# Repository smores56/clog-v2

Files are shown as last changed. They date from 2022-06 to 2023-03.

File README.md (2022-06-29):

The Clog V2
===========

The Clog V2 is a 34-key split keyboard. It has the following features:

- Choc V1 switches
- Wireless only with Seeeduino Xiao BLE controllers
- Pinky clusters (top pinky keys on the sides)
- Splay (4° between middle and ring, 8° between ring and pinky)
- SplitKB puck support for tenting
- EVQWGD001 roller support

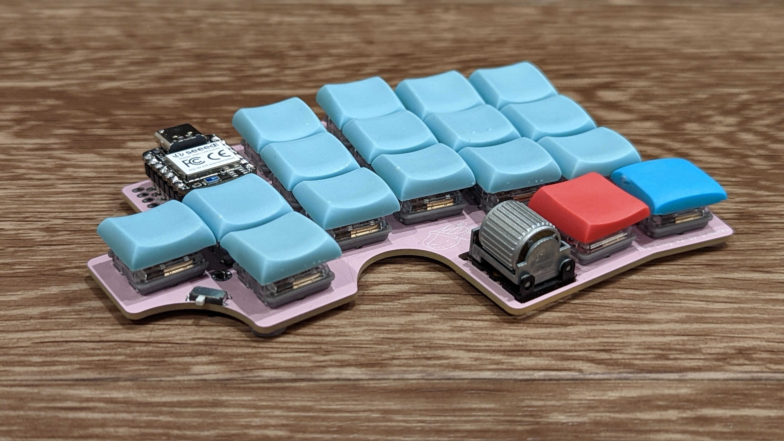
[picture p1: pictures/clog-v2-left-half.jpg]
One Half of the Clog V2


## How to Order

The [gerber ZIP](./clog-v2.zip) has everything you'll need to get this printed.
You can order from [JLC](https://jlcpcb.com) by just uploading that ZIP archive and keeping
the default options. I'd suggest removing the order number, otherwise they'll put
one on the board somewhere randomly.

## Building

### Parts Needed

Part Name            | Quantity        | Notes                                    | Link
--------------------:|:---------------:|:----------------------------------------:|:----
PCB                  | 2 (halves)      |                                          | Look up hurr hurr
Choc V1 Switches     | 34              |                                          | <https://mkultra.click/choc-switches>
Choc Keycaps         | 34              |                                          | <https://mkultra.click/mbk-factory-colors>
SMD Diodes           | 34              |                                          | <https://www.aliexpress.com/item/3256802562651339.html>
Power Switches       | 2               | Technically optional                     | <https://www.digikey.com/en/products/detail/nidec-copal-electronics/CUS-12TB/1124222>
Xiao BLE             | 2               | Not technically optional                 | <https://www.seeedstudio.com/Seeed-XIAO-BLE-nRF52840-p-5201.html>
Small LiPo Batteries | 2               |                                          | <https://www.aliexpress.com/item/2251832610867849.html>
Inch of Copper Wire  | 1               | Use thin and sheathed                    | Any hardware store
MCU Sockets          | 1 strip to chop | Optional, chop into sections of 7 pins   | <https://www.digikey.com/en/products/detail/mill-max-manufacturing-corp/316-43-164-41-006000/1212147>
MCU Socket Pins      | 28              | Optional, buy extras, these are slippery | <https://www.digikey.com/en/products/detail/mill-max-manufacturing-corp/3320-0-00-15-00-00-03-0/4147392>

### Tips

I'd solder the parts in this order:

- Diodes
- Power switches
- MCU sockets/Headers that came with the Xiao's
- MCU pins if you're [socketing](https://docs.splitkb.com/hc/en-us/articles/360011263059-How-do-I-socket-a-microcontroller-)
- Batteries (To the +ve and -ve terminals)
- The "bodge" wire from the +ve charging pad on the controller to the "Bdg" hole
- Choc switches

## Pictures

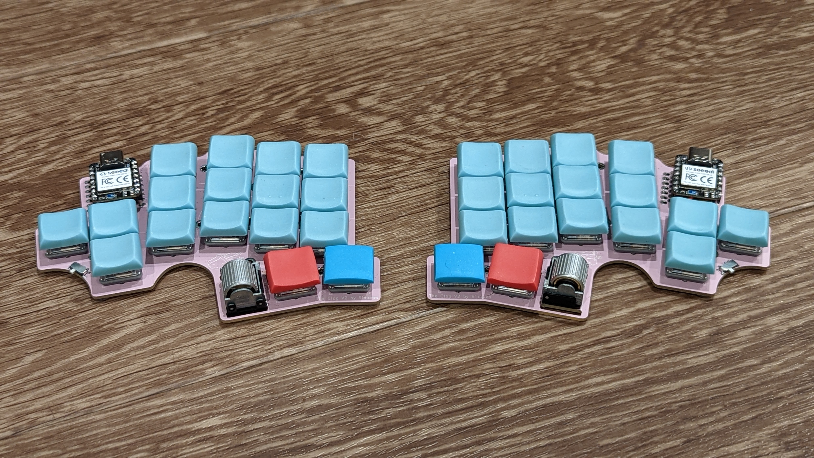
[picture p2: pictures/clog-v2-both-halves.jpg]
The Clog V2


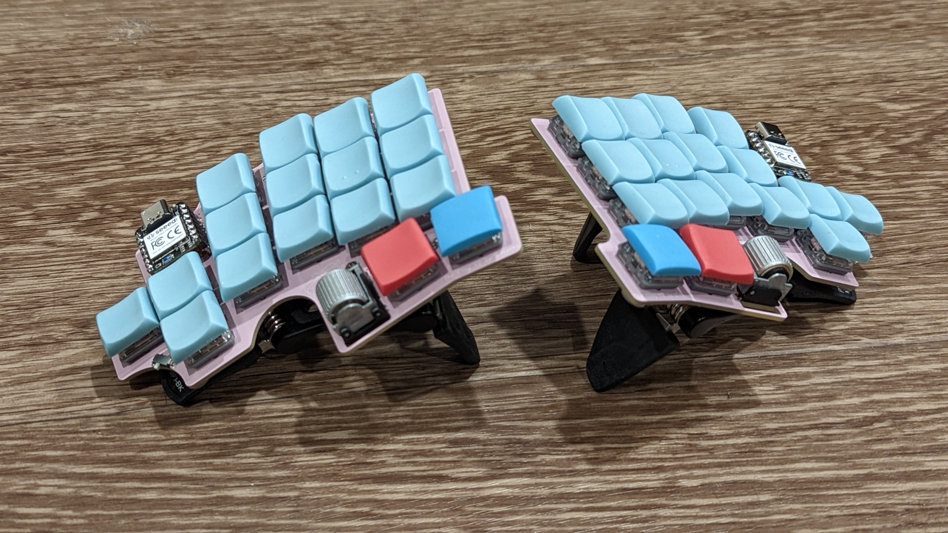
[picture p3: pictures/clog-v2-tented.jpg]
Tented with Pucks and Manfrotto Tripods


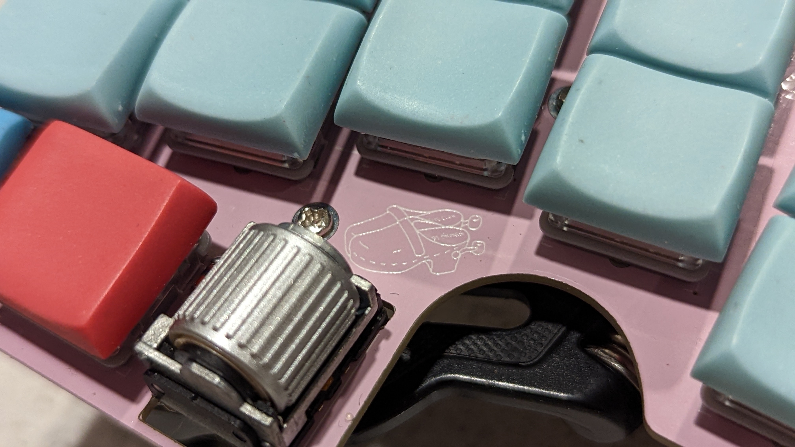
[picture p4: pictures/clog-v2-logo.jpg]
The Clog Logo


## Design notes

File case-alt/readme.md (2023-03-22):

build notes
=====

* uses m2 x 6mm self tapping screw for general assembly
* choose either bottom-flat or bottom-18650
* mcu cap is optional, and it interfer with your fingers depending on typing style
* with 2mm high bumpons, the pcb can "float" inside the case. Leave the m2 just
tight enough to keep it from sliding around.
* 18650 battery holder might need lengthening or shortening depending on whether
your battery is protected or have a bump at the end.

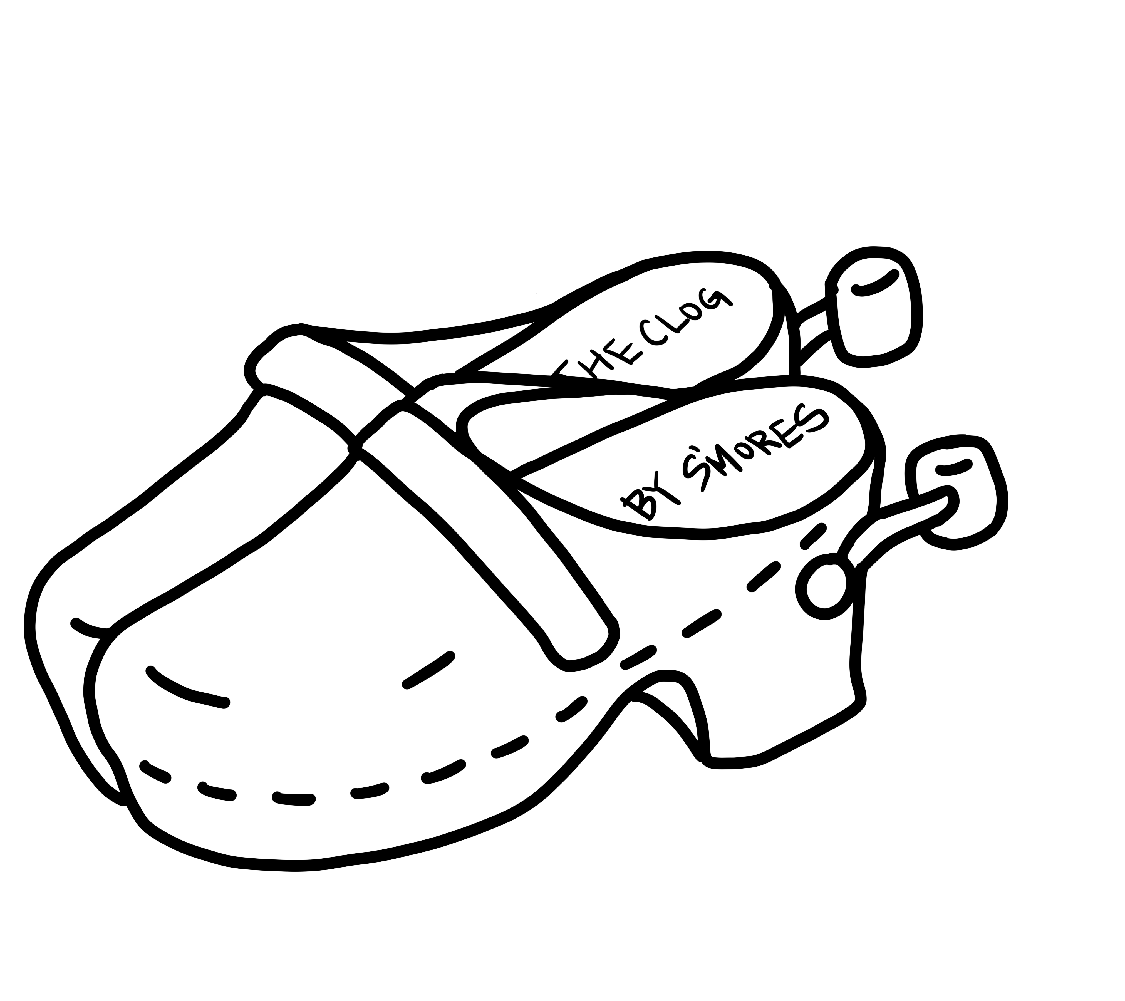
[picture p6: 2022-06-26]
art/clogs.png

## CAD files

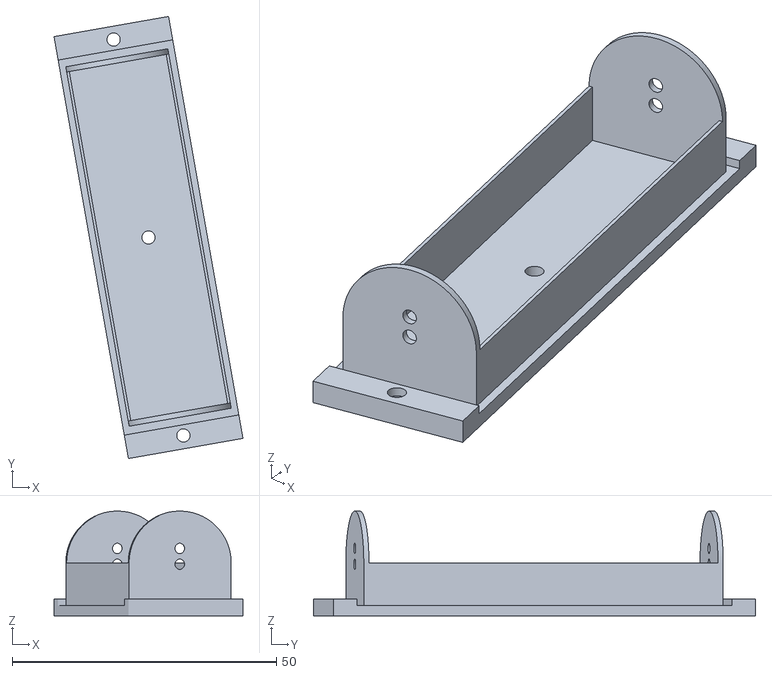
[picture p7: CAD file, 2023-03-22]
case-alt/battery-holder-18650.stl
35.7 x 83.6 x 19.8

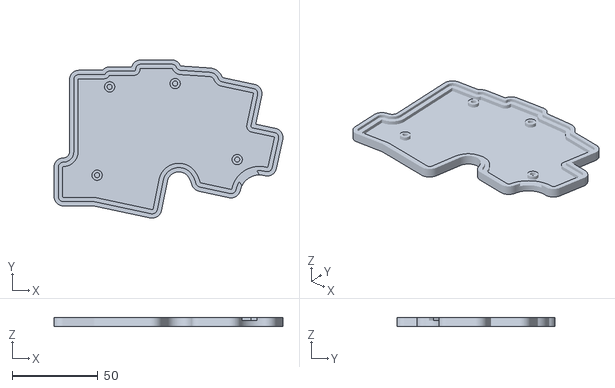
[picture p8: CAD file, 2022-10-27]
case/clog-v2-right.stl
133.2 x 92.1 x 5.10

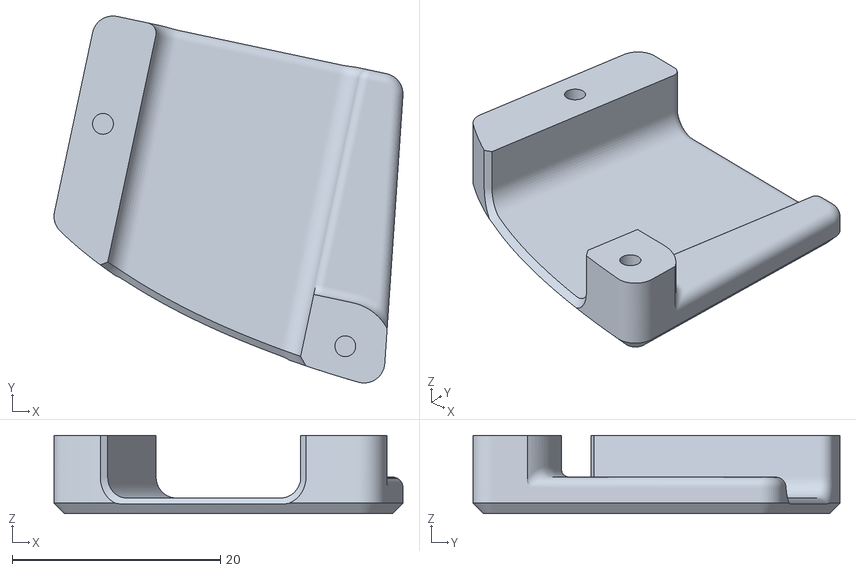
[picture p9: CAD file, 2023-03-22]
case-alt/mcu-cap.stl
33.5 x 35.2 x 7.50

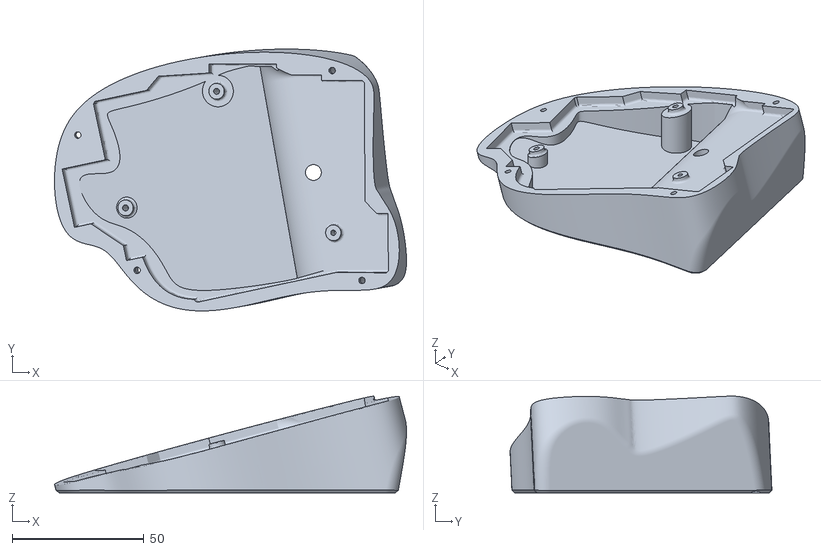
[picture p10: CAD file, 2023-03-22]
case-alt/bottom-18650.stl
133.6 x 99.4 x 36.7

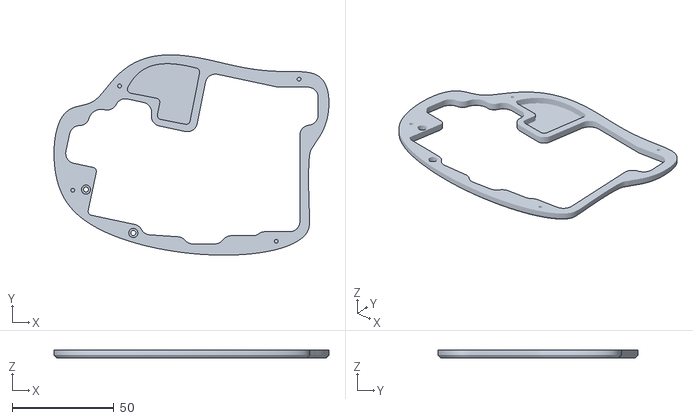
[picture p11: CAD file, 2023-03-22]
case-alt/top.stl
135.2 x 98.4 x 4.00

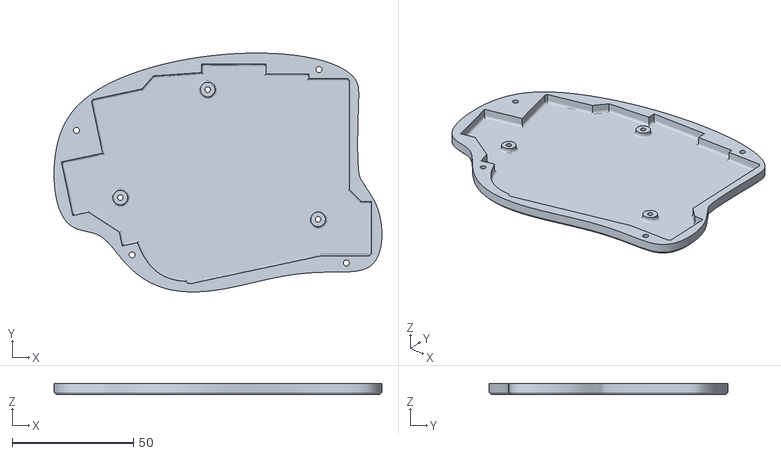
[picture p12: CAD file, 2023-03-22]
case-alt/bottom-flat.stl
135.2 x 98.4 x 4.70

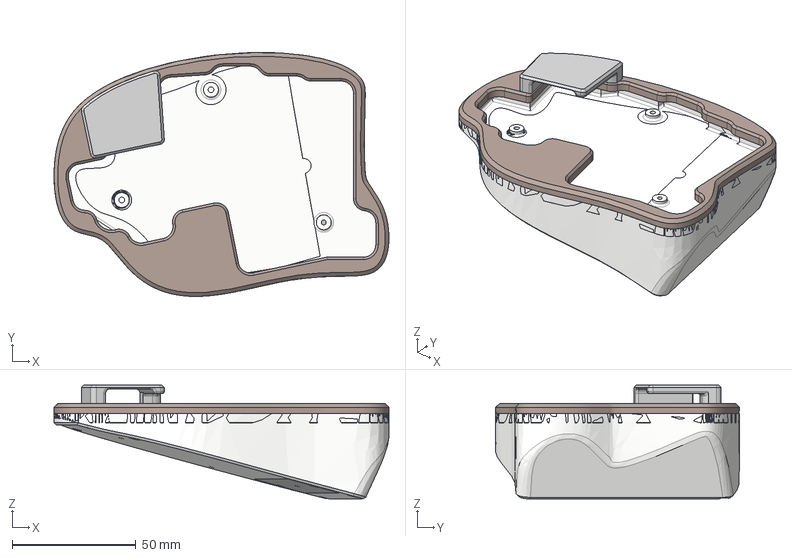
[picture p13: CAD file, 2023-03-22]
case-alt/case-alt.step
135.2 x 98.4 x 45.9 mm
top
bottom
battery holder

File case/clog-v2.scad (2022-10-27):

hole_locations = [
    [48, -0.2],
    [11.9, -44.4],
    [86.1, -2.1],
    [93.4, -53.5],
];

pcb_thickness = 1.6;
component_thickness = 2;
case_thickness = 1.5;
total_thickness = pcb_thickness +
    component_thickness + case_thickness;

heat_insert_radius = 1.5;
strut_radius = 3;

accuracy = 100;

right_side = false;

module pcb() {
    translate([-100, -150, 0])
    import("clog-v2.svg", $fn=accuracy);
}

module pcb_ghost() {
    %
    translate([0, 0, case_thickness + component_thickness])
    linear_extrude(pcb_thickness)
    pcb();
}

module pcb_cutout() {
    translate([0, 0, case_thickness + component_thickness])
    linear_extrude(pcb_thickness + 0.1)
    offset(1.5, $fn=accuracy)
    pcb();
}

module component_cutout() {
    translate([0, 0, case_thickness])
    linear_extrude(component_thickness + pcb_thickness + 0.1)
    offset(-1, $fn=accuracy)
    pcb();
}

module case_body() {
    linear_extrude(total_thickness)
    offset(4, $fn=accuracy)
    pcb();
}

module heat_insert_holes() {
    for (location = hole_locations) {
        translate([location[0], location[1], case_thickness + component_thickness - 3])
        linear_extrude(10)
        circle(heat_insert_radius, $fn=accuracy);
    }
}

module heat_insert_struts() {
    for (location = hole_locations) {
        translate([location[0], location[1], case_thickness - 0.1])
        linear_extrude(component_thickness)
        circle(strut_radius, $fn=accuracy);
    }
}

module power_switch_cutout() {
    translate([5, -55, case_thickness + component_thickness + 2.5])
    rotate([0, 0, -32])
    cube([12, 6, 5], center=true);
}

module full_case() {
    difference() {
        union() {
            difference() {
                case_body();
                pcb_cutout();
                component_cutout();
                power_switch_cutout();
            };
            heat_insert_struts();
        };
        heat_insert_holes();
        pcb_ghost();
    };
}

if (right_side) {
    translate([110, 0, 0])
    mirror([1, 0, 0])
    full_case();
} else {
    full_case();
};

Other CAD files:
case/clog-v2-left.stl

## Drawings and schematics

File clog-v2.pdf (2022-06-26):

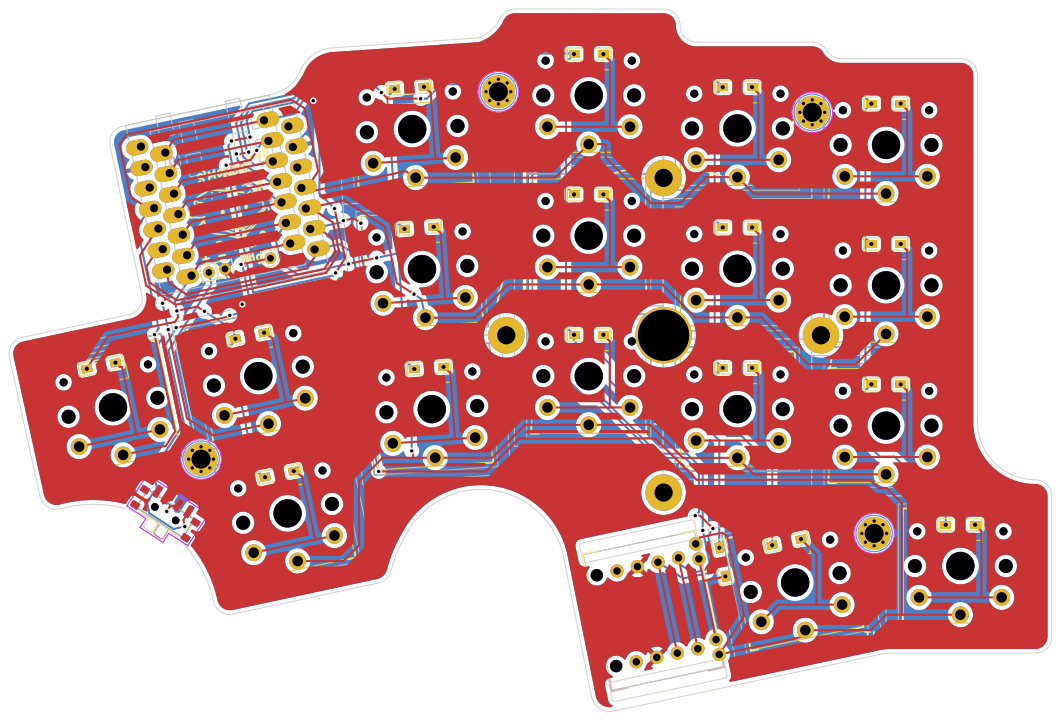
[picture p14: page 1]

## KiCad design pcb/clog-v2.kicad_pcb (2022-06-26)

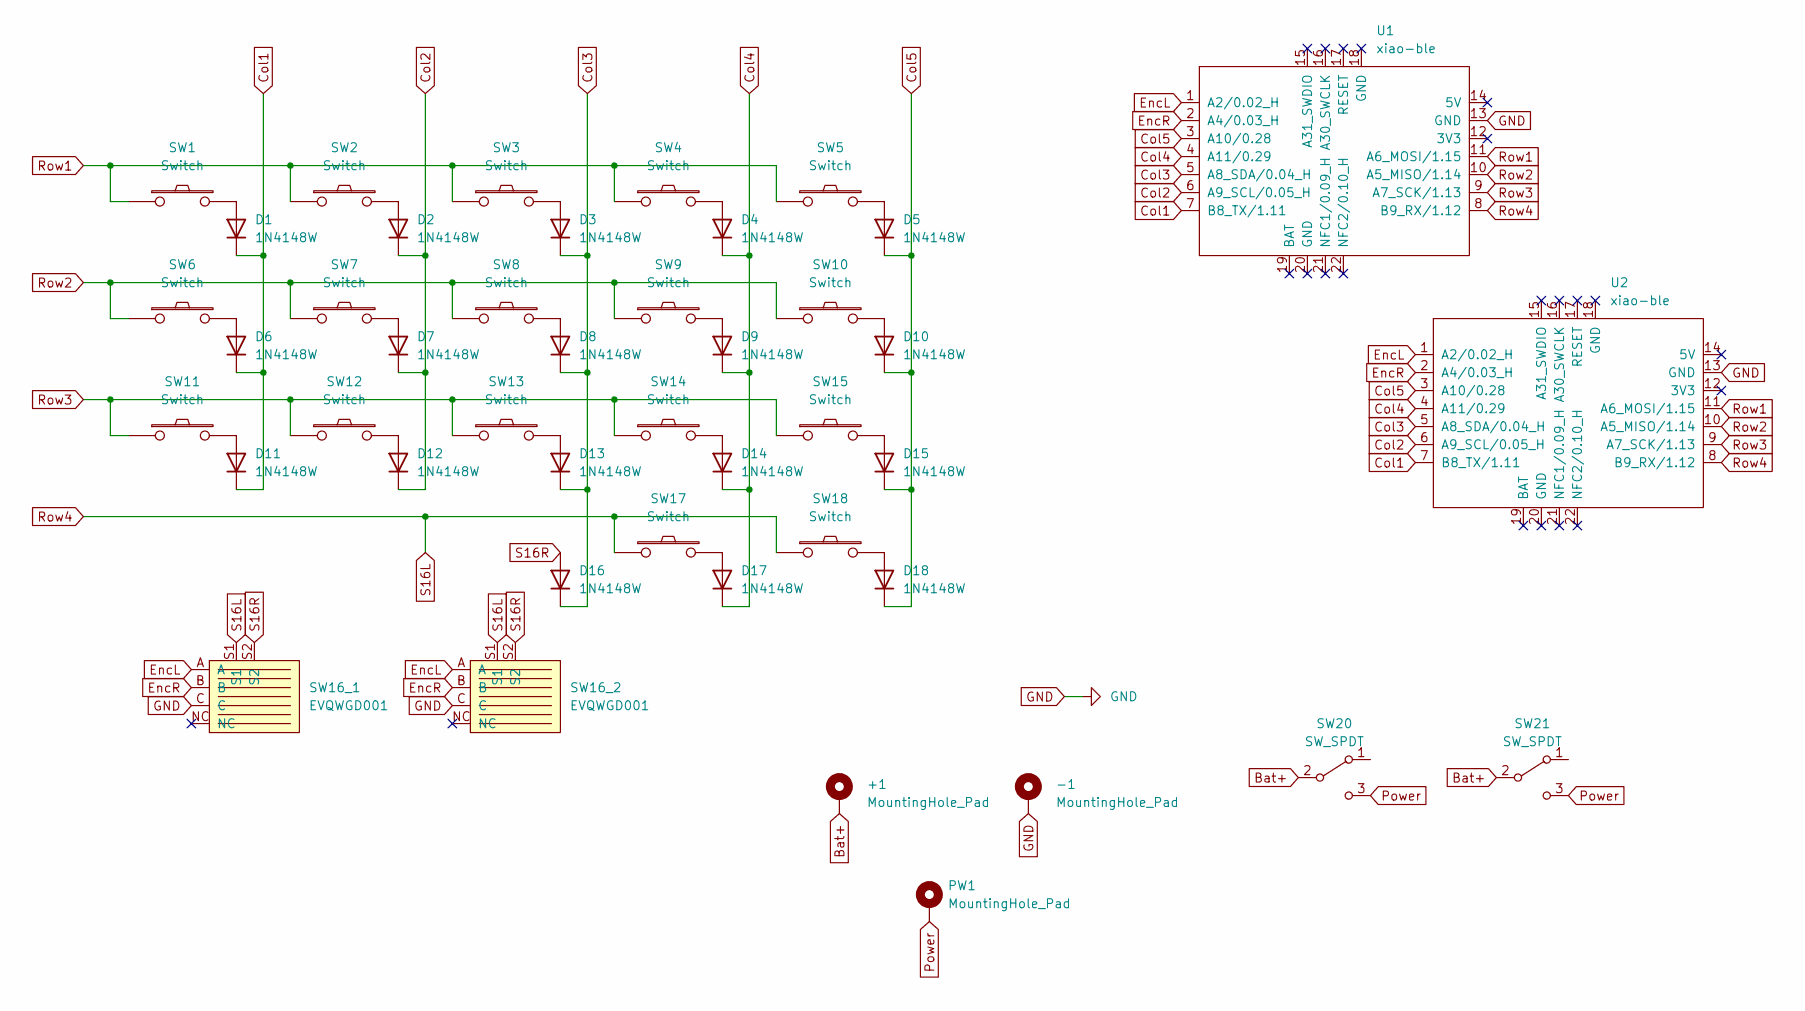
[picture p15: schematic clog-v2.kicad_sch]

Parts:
+1: MountingHole_Pad; single-pin
-1: MountingHole_Pad; single-pin
D1, D2, D3, D4, D5, D6, D7, D8, D9, D10, D11, D12, D13, D14, D15, D16, D17, D18: 1N4148W; smd-diode
PW1: MountingHole_Pad; single-pin
SW1, SW2, SW3, SW4, SW5, SW6, SW7, SW8, SW9, SW10, SW11, SW12, SW13, SW14, SW15, SW17, SW18: Switch; choc-switch-solder-only
SW16_1, SW16_2: EVQWGD001; evq
SW20, SW21: SW_SPDT; SW_SPDT_PCM12
U1, U2: xiao-ble

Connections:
Bat+: +1.1, SW20.2 (B), SW21.2 (B)
Col1: D1.1 (K), D6.1 (K), D11.1 (K), U1.7 (B8_TX/1.11), U2.7 (B8_TX/1.11)
Col2: D2.1 (K), D7.1 (K), D12.1 (K), U1.6 (A9_SCL/0.05_H), U2.6 (A9_SCL/0.05_H)
Col3: D3.1 (K), D8.1 (K), D13.1 (K), D16.1 (K), U1.5 (A8_SDA/0.04_H), U2.5 (A8_SDA/0.04_H)
Col4: D4.1 (K), D9.1 (K), D14.1 (K), D17.1 (K), U1.4 (A11/0.29), U2.4 (A11/0.29)
Col5: D5.1 (K), D10.1 (K), D15.1 (K), D18.1 (K), U1.3 (A10/0.28), U2.3 (A10/0.28)
EncL: SW16_1.A, SW16_2.A, U1.1 (A2/0.02_H), U2.1 (A2/0.02_H)
EncR: SW16_1.B, SW16_2.B, U1.2 (A4/0.03_H), U2.2 (A4/0.03_H)
GND: -1.1, SW16_1.C, SW16_2.C, U1.13 (GND), U2.13 (GND)
unnamed: D1.2 (A), SW1.2
unnamed: D2.2 (A), SW2.2
unnamed: D3.2 (A), SW3.2
unnamed: D4.2 (A), SW4.2
unnamed: D5.2 (A), SW5.2
unnamed: D6.2 (A), SW6.2
unnamed: D7.2 (A), SW7.2
unnamed: D8.2 (A), SW8.2
unnamed: D9.2 (A), SW9.2
unnamed: D10.2 (A), SW10.2
unnamed: D11.2 (A), SW11.2
unnamed: D12.2 (A), SW12.2
unnamed: D13.2 (A), SW13.2
unnamed: D14.2 (A), SW14.2
unnamed: D15.2 (A), SW15.2
unnamed: D17.2 (A), SW17.2
unnamed: D18.2 (A), SW18.2
Power: PW1.1, SW20.3 (C), SW21.3 (C)
Row1: SW1.1, SW2.1, SW3.1, SW4.1, SW5.1, U1.11 (A6_MOSI/1.15), U2.11 (A6_MOSI/1.15)
Row2: SW6.1, SW7.1, SW8.1, SW9.1, SW10.1, U1.10 (A5_MISO/1.14), U2.10 (A5_MISO/1.14)
Row3: SW11.1, SW12.1, SW13.1, SW14.1, SW15.1, U1.9 (A7_SCK/1.13), U2.9 (A7_SCK/1.13)
Row4: SW16_1.S1, SW16_2.S1, SW17.1, SW18.1, U1.8 (B9_RX/1.12), U2.8 (B9_RX/1.12)
S16R: D16.2 (A), SW16_1.S2, SW16_2.S2

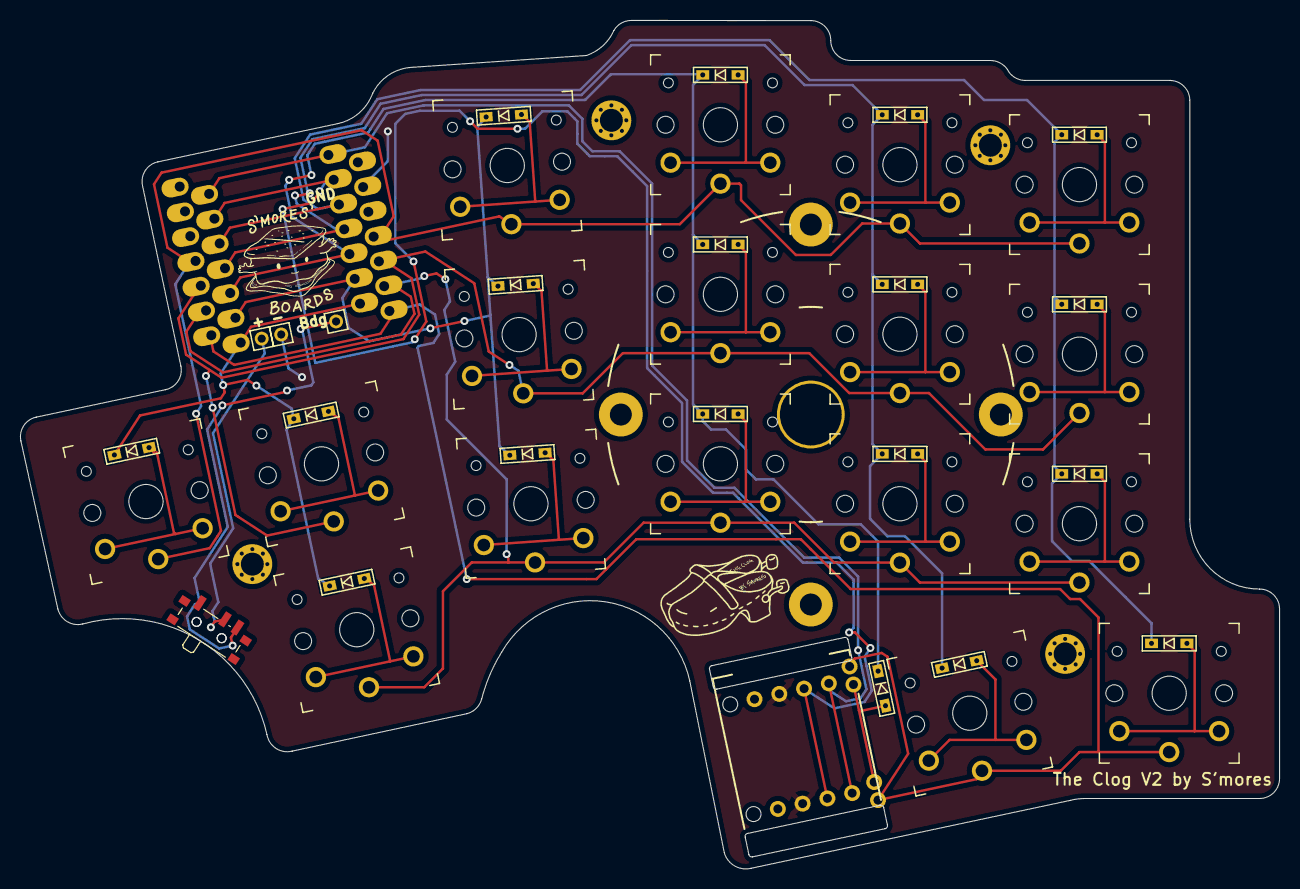
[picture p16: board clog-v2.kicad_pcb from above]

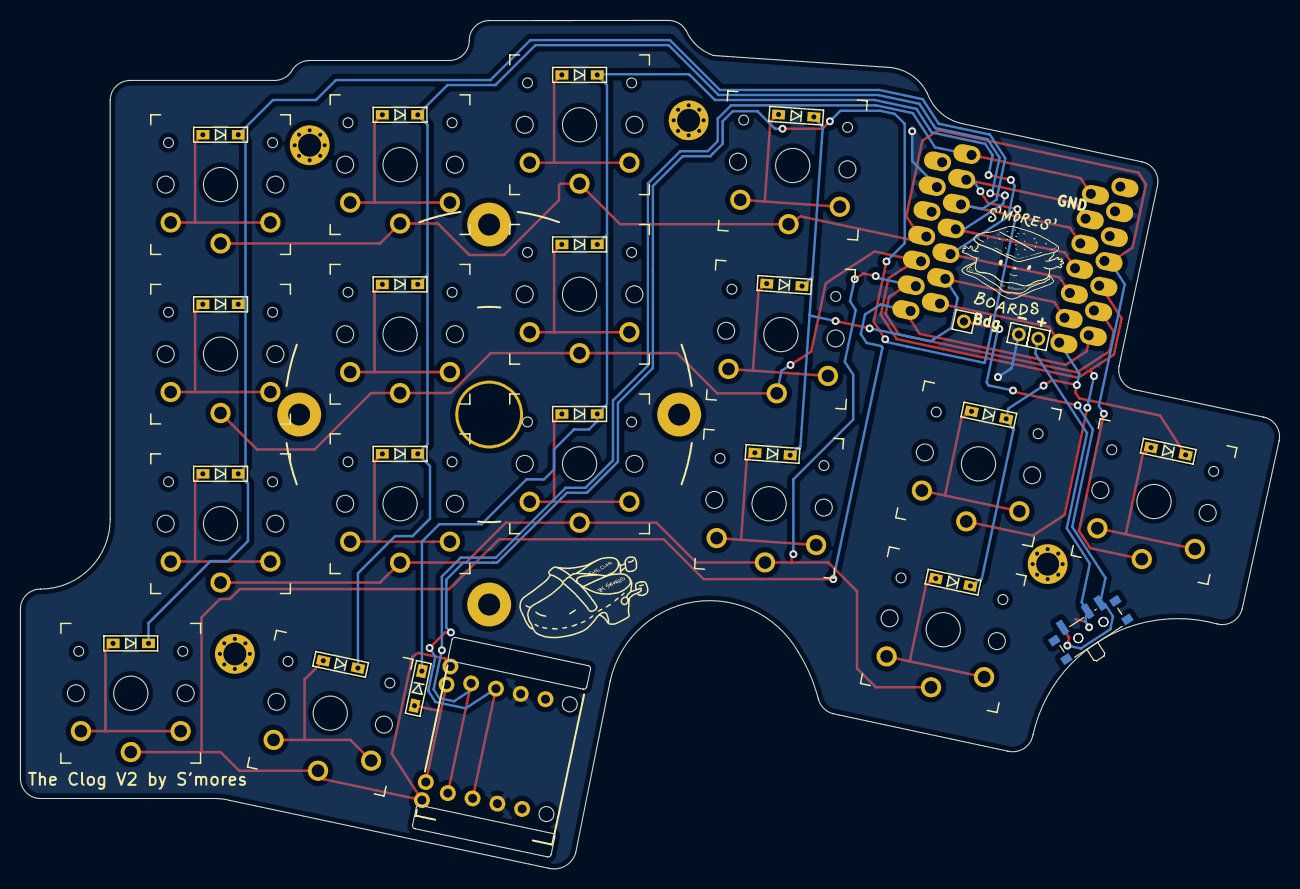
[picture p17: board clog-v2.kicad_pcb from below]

Board: 2 copper layers, 126.3 x 85.1 mm, 48 parts (3 on the bottom side), 32 nets.

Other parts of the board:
Ref**: Val**; m2-hole
Ref**#2, Ref**#3, Ref**#4: Val**; m2-hole

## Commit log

2022-06-26 Finished Design
    [clog-v2.kicad_pcb, clog-v2.kicad_sch]
2022-06-26 Add Printout
2022-10-27 Add a Flat Case
    [clog-v2-left.stl, clog-v2-right.stl, clog-v2.scad]
2023-03-22 adding case
    [battery-holder-18650.stl, bottom-18650.stl, bottom-flat.stl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]
2023-03-22 laying stls flat
    [battery-holder-18650.stl, mcu-cap.stl]
2023-03-22 more STL plating
    [top.stl]
